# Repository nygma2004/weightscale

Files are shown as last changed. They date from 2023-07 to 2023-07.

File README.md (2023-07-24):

# Water Intake Monitor and Enforcement System

This is a ESP8266, ESPHome, Node-Red project to monitor how much water I drink throughout the day when I work from home and notify me to drink from time to time.
It is using an ESP Wemos D1 mini as a processor, load cell (strain gauge) to measure the weight of the water bottle, neopixel ring light for visual notification. The ESP runs an ESPHome sketch, communication is done over MQTT and the logic is implemented in Node-Red.

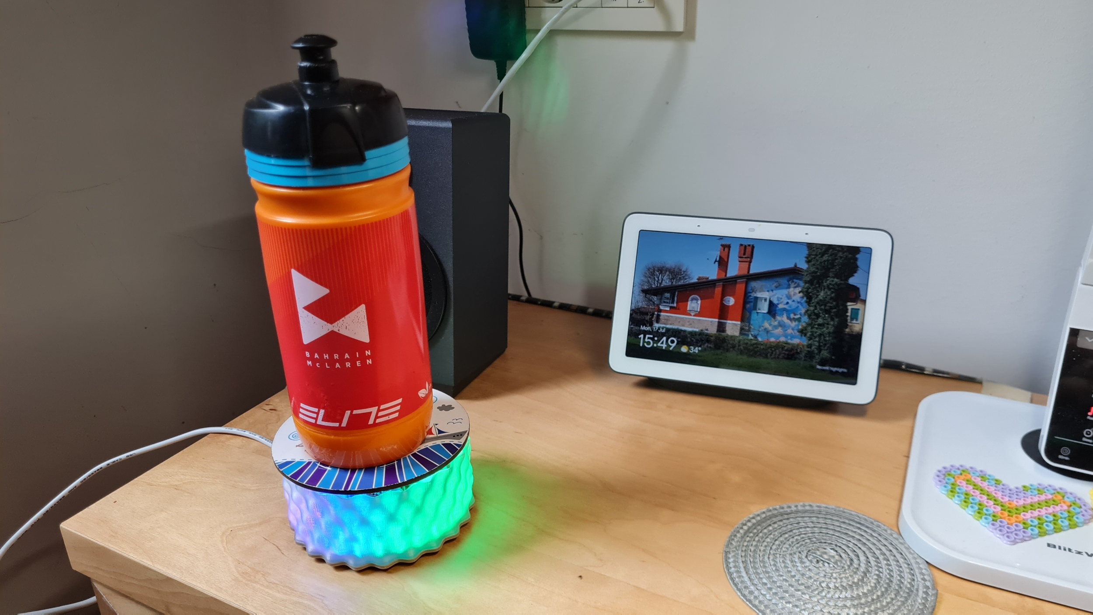
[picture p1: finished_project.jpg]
Finished Project


The logic does the following:
- Detects that a bottle is placed on the weight and stores the weight.
- Detects if the weight is reducing, assuming that water is consumed. This consumption is recorded and accumulated.
- When the weight increases, the logic assumes the bottle has been re-filled.
- If the weight is not changing, notification is sent and further reminder notification if there is no change.
- Ring light is used for visual notification, and the Node-Red code also includes example for Telegram message.
- If a goal is reached, no more notification is sent.
- If the weight is empty (bottle removed), no notification is sent at all.
- All logic is implemented in Node-Red, ESP just sends readings and receives messages to turn the light on/off.
- Main parameters of the code is configurable in Node-Red.

There is a detailed video on this project where all the details are explained:

Project video (https://www.youtube.com/watch?v=myc7lB9ZL7s)

## Hardware

The hardware is an ESP8266 microcontroller running ESPHome firmware. You need the following hardware for this project:
- ESP6288 Wemos D1 Mini: I don't have a recent Aliexpress link, you can find these everywhere.
- 1kg Load cell with HX711 amplifier board: https://www.aliexpress.com/item/33046037411.html
- 24 pixel WS2812 ring light: https://www.aliexpress.com/item/32963152993.html

The wiring diagram is here:

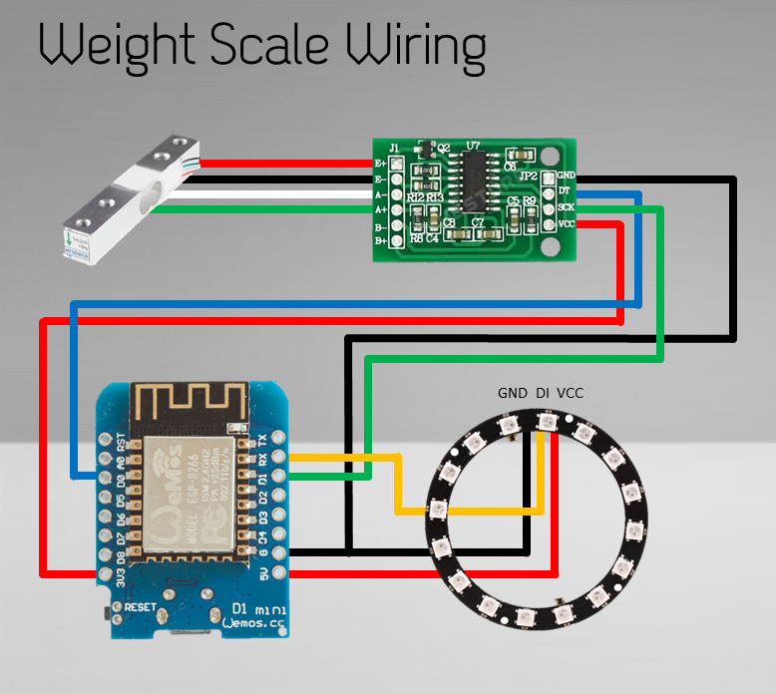
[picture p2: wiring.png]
Wiring diagram


In order for the load cell to work, one side of the load cell needs to be supported from the "underside". The weight must be applied on the other end from the "top". Make sure the actual load cell elements (under the white glue) are free and not weight is applied to them.

Load cell is shipped with the red/black/white/green wires attached. `B-` and `B+` connections are not used.
```
Load cell  HX711 board
red        E+
black      E-
white      A-
green      A+
```

```
HX711 board  Wemos D1 Mini
GND          G (GND)
DT           D0
SCK          D1
VCC          3V3
```

```
Wemos D1 Mini  Ring Light
GND            GND
RX             DI
5V             VCC
```

## ESPHome

You can find my ESPHome yaml file in the repo: [weight.yaml](weight.yaml) and also the [secrets.yaml](secrets.yaml) in which the IDs and password are stored separately.
Obviously update your credential details in the `secrets.yaml` file and there is where all the settings are stored. But the load cell needs to be calibrated in the main `weight.yaml` file. This process is again explained in the video.

## Case

I have designed a 3D printed case for this project. Is consists of a base [WaterScale_Stand.stl](WaterScale_Stand.stl) and a separate side [WaterScale_Wavy side.stl](WaterScale_Wavy side.stl) which is printed from a transparent filament. I designed both parts to be printed without support. I also used some felt feets so the scale does not slide around the table.
The top of the scale is cut from 4mm acrylic. I also have the 2D drawings for that [weight_plate.dxf](weight_plate.dxf).I cut this on my CNC router, but you can use a jigsaw as well, and for the spacer just use stack of washers.

## Node-Red Flow

All the logic is implemented in the Node-Red flow. It receives continous updates from the load cell and sends status changes which controls the ring light and issues the Telegram messages.
There is an inject node on the top of the flow and all the configuration details are stored there. Check the comment node next to it for explanation for each settings.
How to implement and configure the flow is explained in the video, and also there is a more in-depth explanation of the actual logic.
There are no special nodes required by this flow.

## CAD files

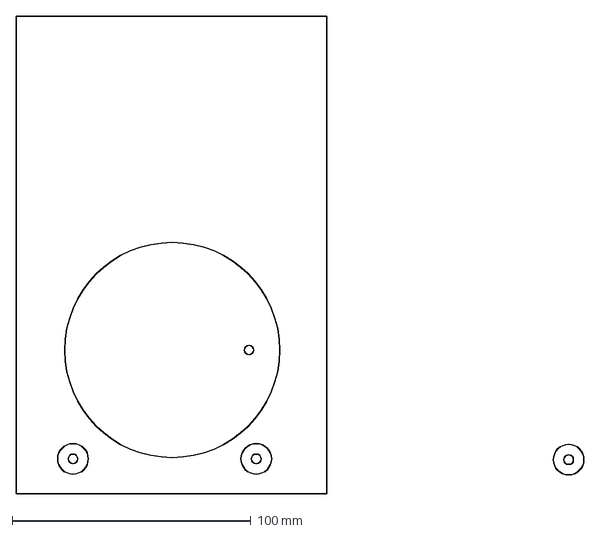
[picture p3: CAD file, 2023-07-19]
weight_plate.dxf
237.7 x 200.0 mm

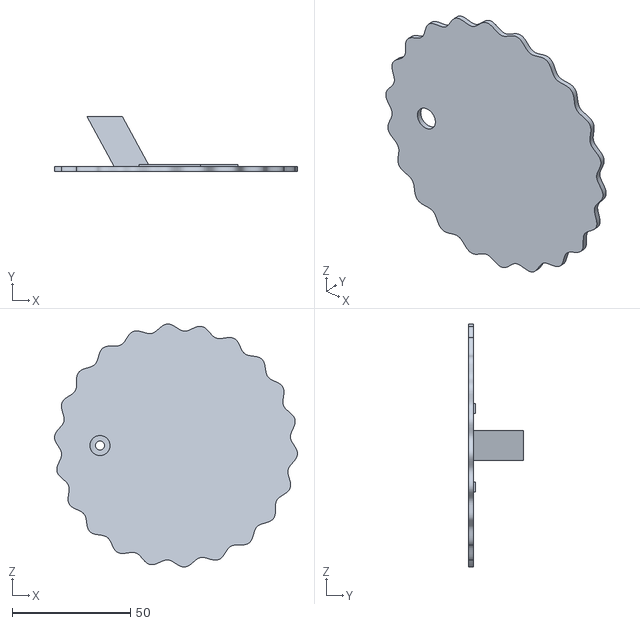
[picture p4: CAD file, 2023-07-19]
WaterScale_Stand.stl
102.7 x 23.1 x 102.7

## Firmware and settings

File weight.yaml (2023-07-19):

substitutions:
  devicename: waterscale

esphome:
  name: $devicename
  platform: ESP8266
  board: d1_mini

# Enable logging
logger:

ota:
  password: !secret ota_password

wifi:
  ssid: !secret wifi_ssid
  password: !secret wifi_password

  # Enable fallback hotspot (captive portal) in case wifi connection fails
  ap:
    ssid: "Watermeter Fallback Hotspot"
    password: "12345678"

captive_portal:

mqtt:
  broker: !secret mqtt_ip
  username: !secret mqtt_user
  password: !secret mqtt_password
  client_id: $devicename

light:
  - platform: neopixelbus
    type: GRB
    variant: WS2812X
    pin: GPIO3
    num_leds: 24
    name: "ringlight"
    state_topic: "$devicename/ringlight/state"
    command_topic: "$devicename/ringlight/command"
    effects:
      # Customize parameters
      - random:
          name: "Slow Random"
          transition_length: 30s
          update_interval: 30s
      - random:
          name: "Fast Random"
          transition_length: 4s
          update_interval: 5s
      - addressable_rainbow:
          name: Rainbow
          speed: 10
          width: 50
      - addressable_twinkle:
          name: Twinkle Effect
          twinkle_probability: 5%
          progress_interval: 4ms
      - addressable_random_twinkle:
          name: Random Twinkle
          twinkle_probability: 5%
          progress_interval: 32ms
      - addressable_fireworks:
          name: Fireworks
          update_interval: 32ms
          spark_probability: 10%
          use_random_color: false
          fade_out_rate: 120
      - addressable_flicker:
          name: Flicker
      - addressable_color_wipe:
          name: Color Wipe
          colors:
            - red: 100%
              green: 100%
              blue: 100%
              num_leds: 1
            - red: 0%
              green: 0%
              blue: 0%
              num_leds: 2
          add_led_interval: 100ms
          reverse: false
      - addressable_scan:
          name: Scan
          move_interval: 2000ms
          scan_width: 1
      - pulse:
          name: "Fast Pulse"
          transition_length: 0.5s
          update_interval: 0.5s
          min_brightness: 0%
          max_brightness: 100%

text_sensor:
  - platform: template
    name: Uptime Human Readable
    id: uptime_human
    icon: mdi:clock-start
    state_topic: $devicename/uptime_text

sensor:
  - platform: hx711
    name: "scale"
    dout_pin: D0
    clk_pin: D1
    gain: 64
    update_interval: 10s
    state_topic: "$devicename/scale/state"
    filters:
      - calibrate_linear:
          - 58700 -> 0
          - 691100 -> 678
    unit_of_measurement: g

# Report Wifi signal strength
  - platform: wifi_signal
    name: "WiFi Signal Sensor"
    update_interval: 60s
    state_topic: $devicename/rssi

# System uptime
  - platform: uptime
    name: Uptime Sensor
    id: uptime_sensor
    state_topic: $devicename/uptime
    update_interval: 60s
    on_raw_value:
      then:
        - text_sensor.template.publish:
            id: uptime_human
            state: !lambda |-
              int seconds = round(id(uptime_sensor).raw_state);
              int days = seconds / (24 * 3600);
              seconds = seconds % (24 * 3600);
              int hours = seconds / 3600;
              seconds = seconds % 3600;
              int minutes = seconds /  60;
              seconds = seconds % 60;
              return (
                (days ? String(days) + "d " : "") +
                (hours ? String(hours) + "h " : "") +
                (minutes ? String(minutes) + "m " : "") +
                (String(seconds) + "s")
              ).c_str();
    filters:
      - lambda: return x / 60;
    unit_of_measurement: "m"

# Web Server for discovery purposes
web_server:
  port: 80

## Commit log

2023-07-19 Node-Red flow
2023-07-19 3D models for the base and side
    [WaterScale_Stand.stl]
2023-07-19 2D files for the top plate
    These are the top acrylic files I CNC cut from 4mm acrylic
    [weight_plate.dxf]
2023-07-19 Wiring diagram
